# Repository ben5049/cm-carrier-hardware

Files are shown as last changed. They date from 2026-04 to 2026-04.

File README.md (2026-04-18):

# Compute Module 5 Carrier Board (WIP)

Compact CM5 carrier board with an M.2 E-key connector and a 1000BASE-T1 Ethernet PHY, as well as other optional IO.

- V1 Uses a separate PCIe switch and PCIe-to-Ethernet bridge. It has been abandoned in favour of V2
- V2 Uses the PCI11010C which integrates a PCIe switch and Ethernet MAC, leading to space and power savings compared to V1

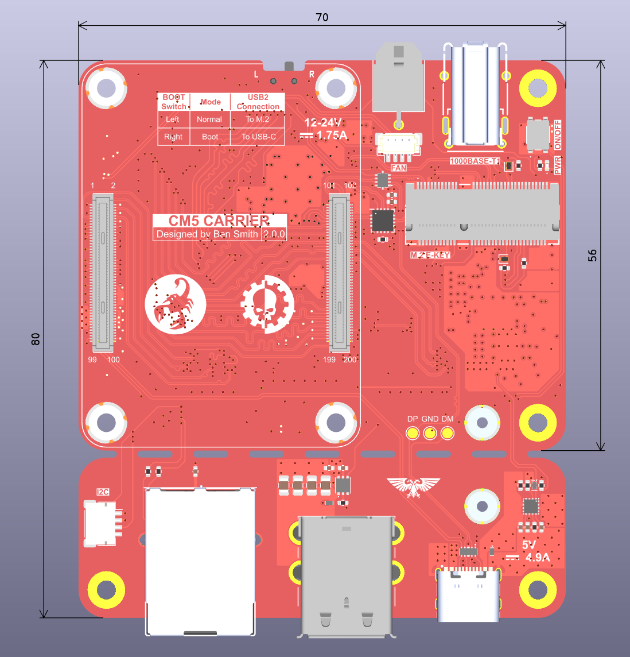
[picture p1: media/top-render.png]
top-render


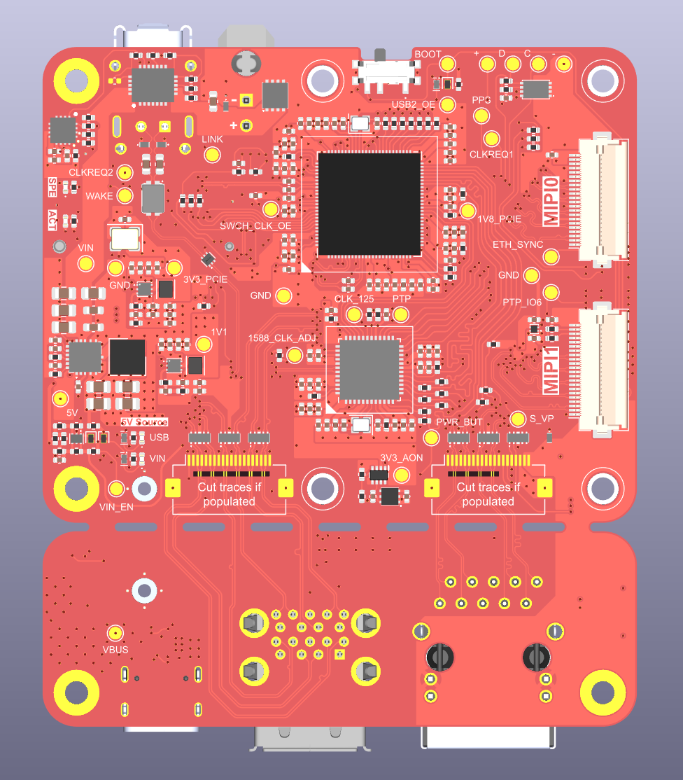
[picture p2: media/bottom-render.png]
bottom-render


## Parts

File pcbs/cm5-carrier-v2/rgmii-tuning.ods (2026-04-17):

tx | Post-r | Pre-r | total length | target | skew
d3 | 44.3194 | 3.2212 | 47.5406 | 44.3196 | 0.000199999999999534
d2 | 44.0708 | 3.4698 | 47.5406 | 44.071 | 0.000200000000006639
d1 | 43.8223 | 3.7183 | 47.5406 | 43.8225 | 0.000200000000006639
d0 | 43.5116 | 4.029 | 47.5406 | 43.5118 | 0.000200000000006639
ctl | 43.036 | 4.5048 | 47.5408 | 43.036 | 0
clk | 42.7582 | 4.7824 | 47.5406 | 42.7584 | 0.000199999999999534
rx | Post-r | Pre-r | total length | target | skew
d3 | 46.7064 | 4.7882 | 51.4946 | 46.7811 | 0.0747000000000071
d2 | 48.6547 | 2.9097 | 51.5644 | 48.6596 | 0.00490000000000634
d1 | 46.1052 | 5.4641 | 51.5693 | 46.1052 | 0
d0 | 46.9834 | 4.5618 | 51.5452 | 47.0075 | 0.0241000000000042
ctl | 46.8961 | 4.6096 | 51.5057 | 46.9597 | 0.0636000000000081
clk | 48.7847 | 2.7182 | 51.5029 | 48.8511 | 0.0664000000000016

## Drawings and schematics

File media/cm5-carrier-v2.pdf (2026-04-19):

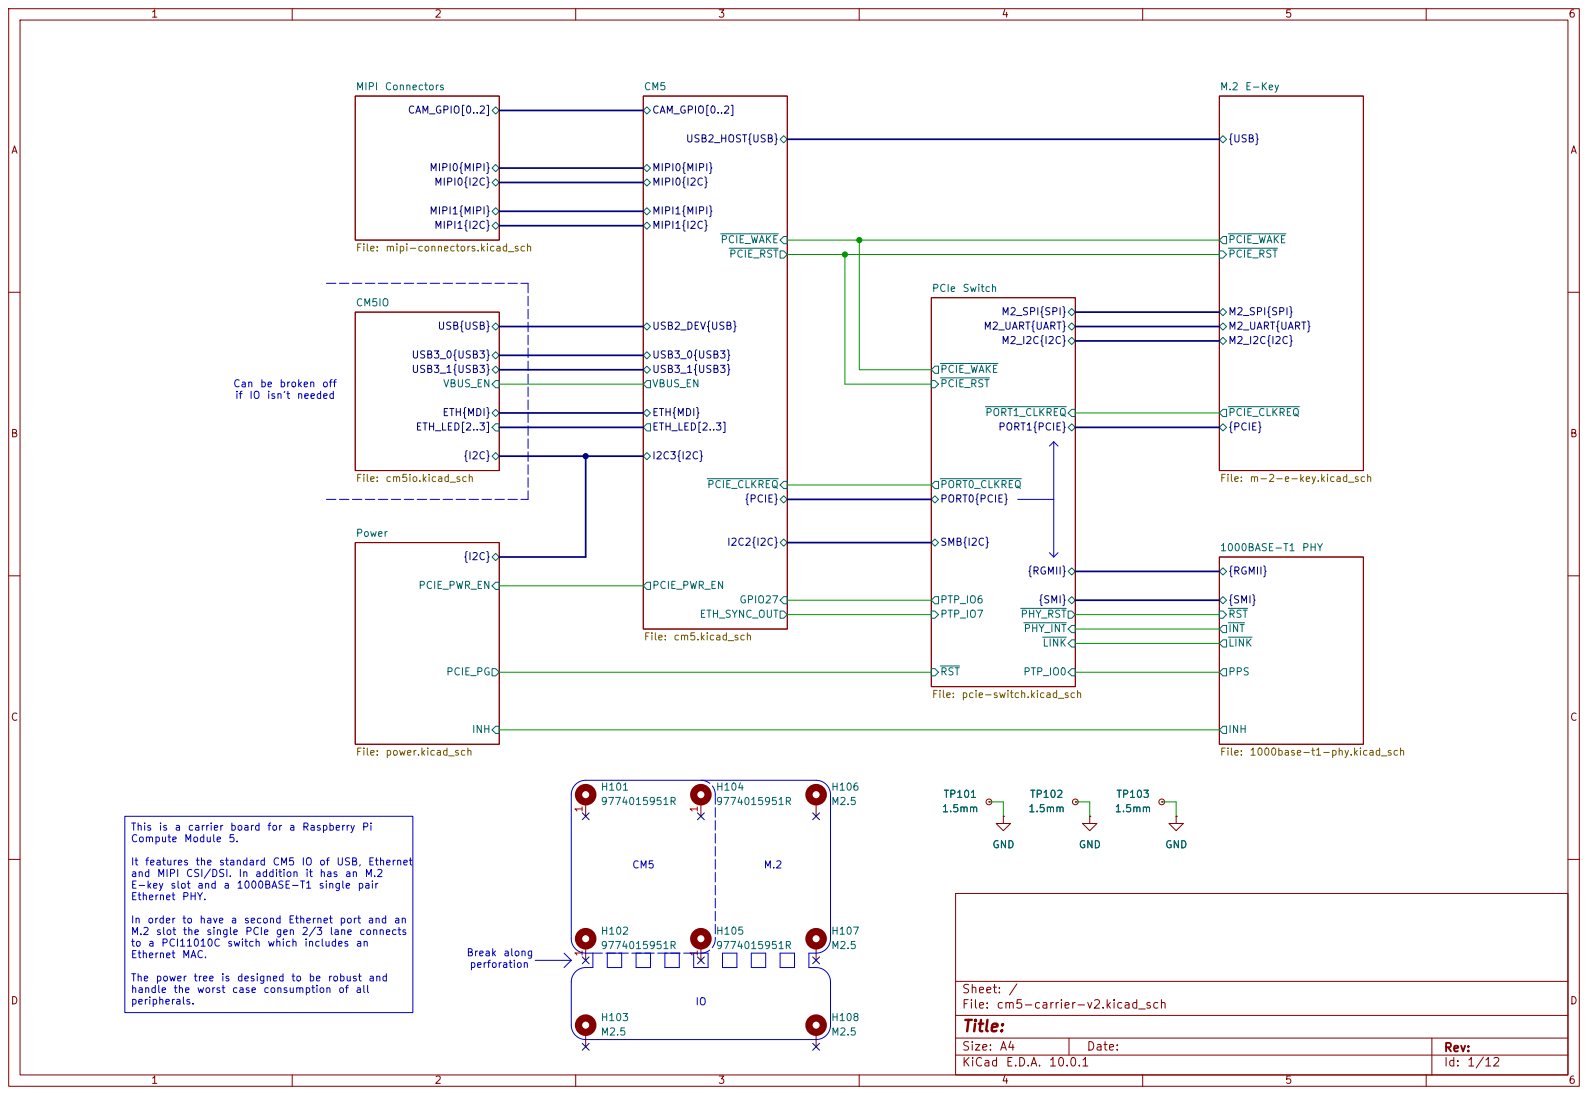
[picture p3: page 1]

CAM_GPIO[0..2] MIPI Connectors File: mipi-connectors.kicad_sch

M2_UART{UART} M.2 E-Key File: m-2-e-key.kicad_sch

Can be broken off
if IO isn't needed

This is a carrier board for a Raspberry Pi Compute Module 5.

It features the standard CM5 IO of USB, Ethernet and MIPI CSI/DSI. In addition it has an M.2

E-key slot and a 1000BASE-T1 single pair Ethernet PHY.

In order to have a second Ethernet port and an M.2 slot the single PCIe gen 2/3 lane connects

to a PCI11010C switch which includes an
Ethernet MAC. The power tree is designed to be robust and

Size: A4 | Rev:
KiCad E.D.A. 10.0.1 | Id: 1/12

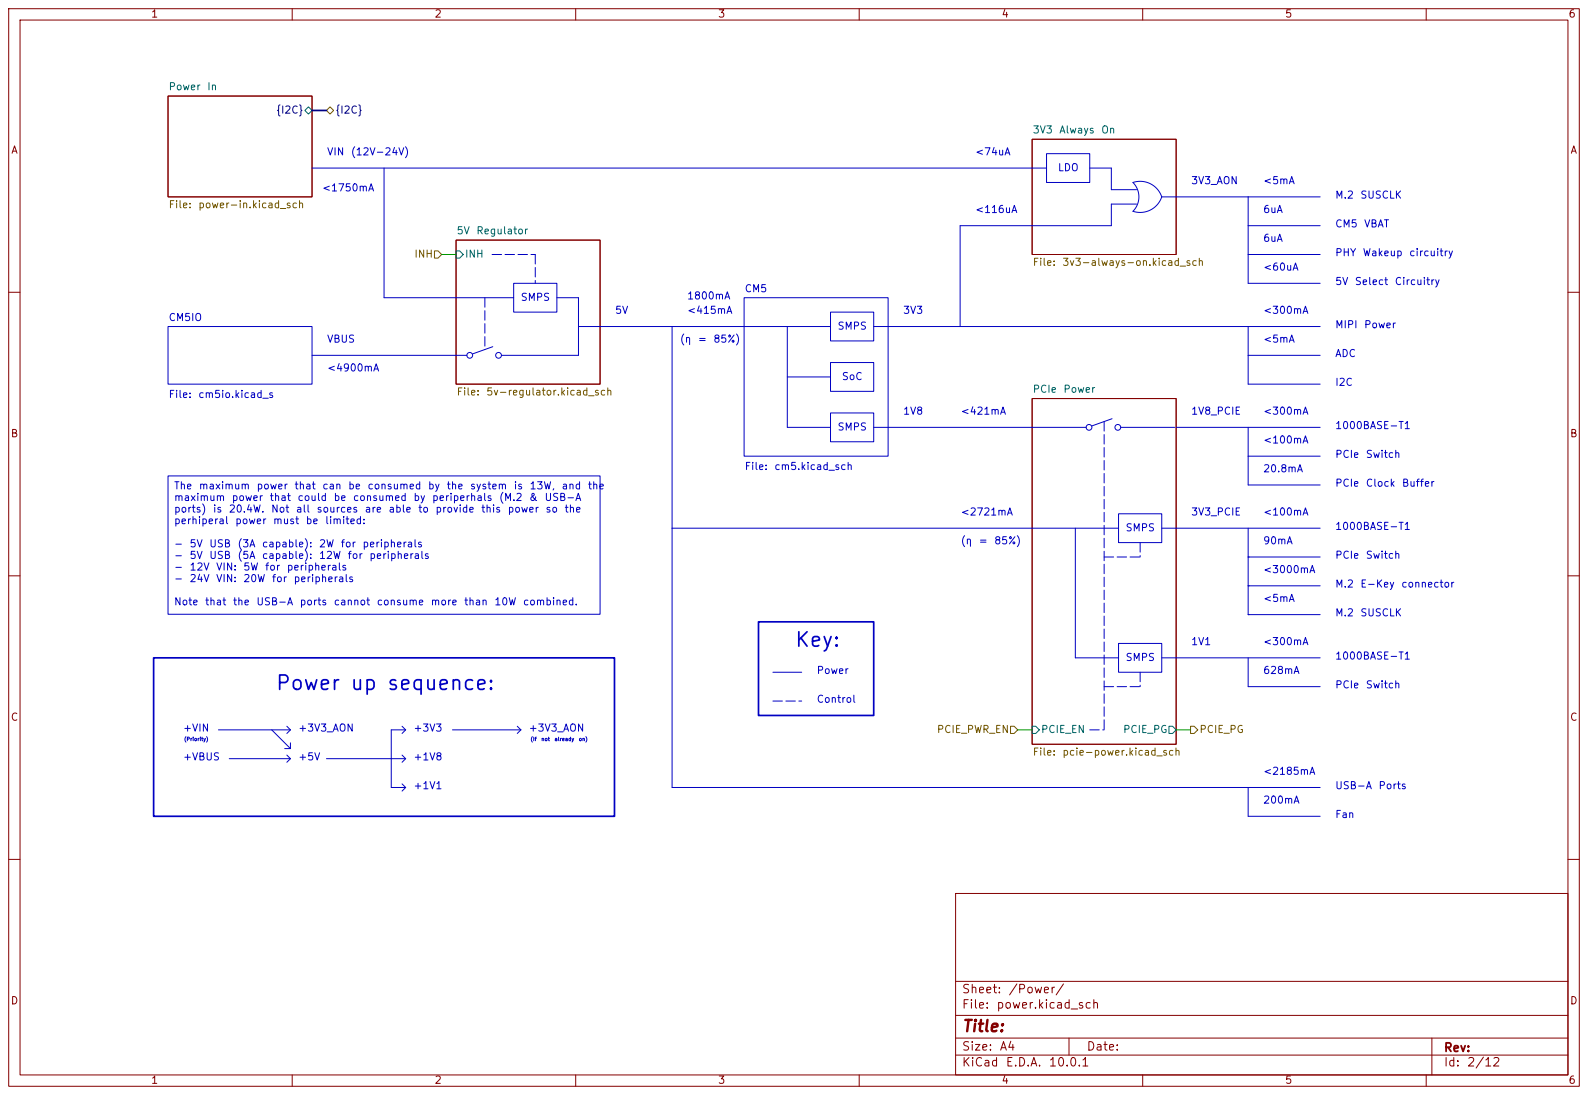
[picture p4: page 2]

5V Select Circuitry CM5 VBAT PCIe Switch 1000BASE-T1 PCIe Clock Buffer M.2 SUSCLK
ADC USB-A Ports 200mA <2185mA
PCIe Power File: pcie-power.kicad_sch

PHY Wakeup circuitry M.2 SUSCLK

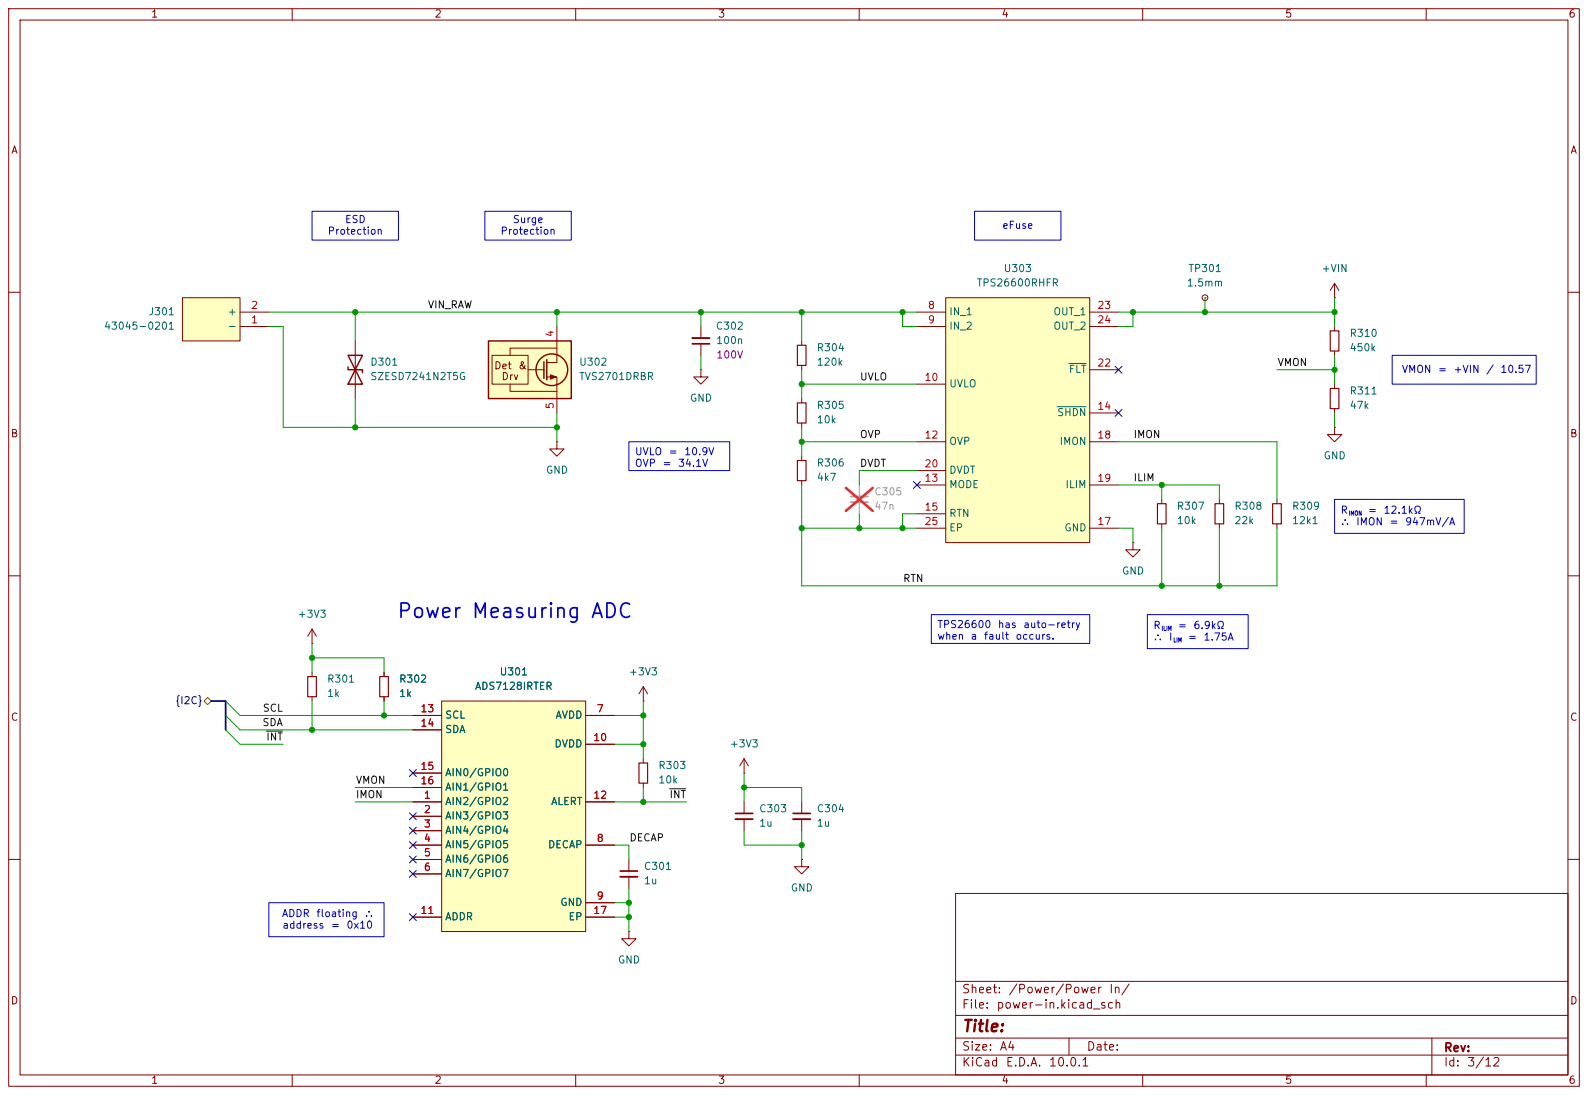
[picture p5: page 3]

eFuse UVLO = 10.9V OVP = 34.1V ESD
Protection

Surge Protection Power Measuring ADC

Sheet: /Power/Power In/
File: power-in.kicad_sch
Title:

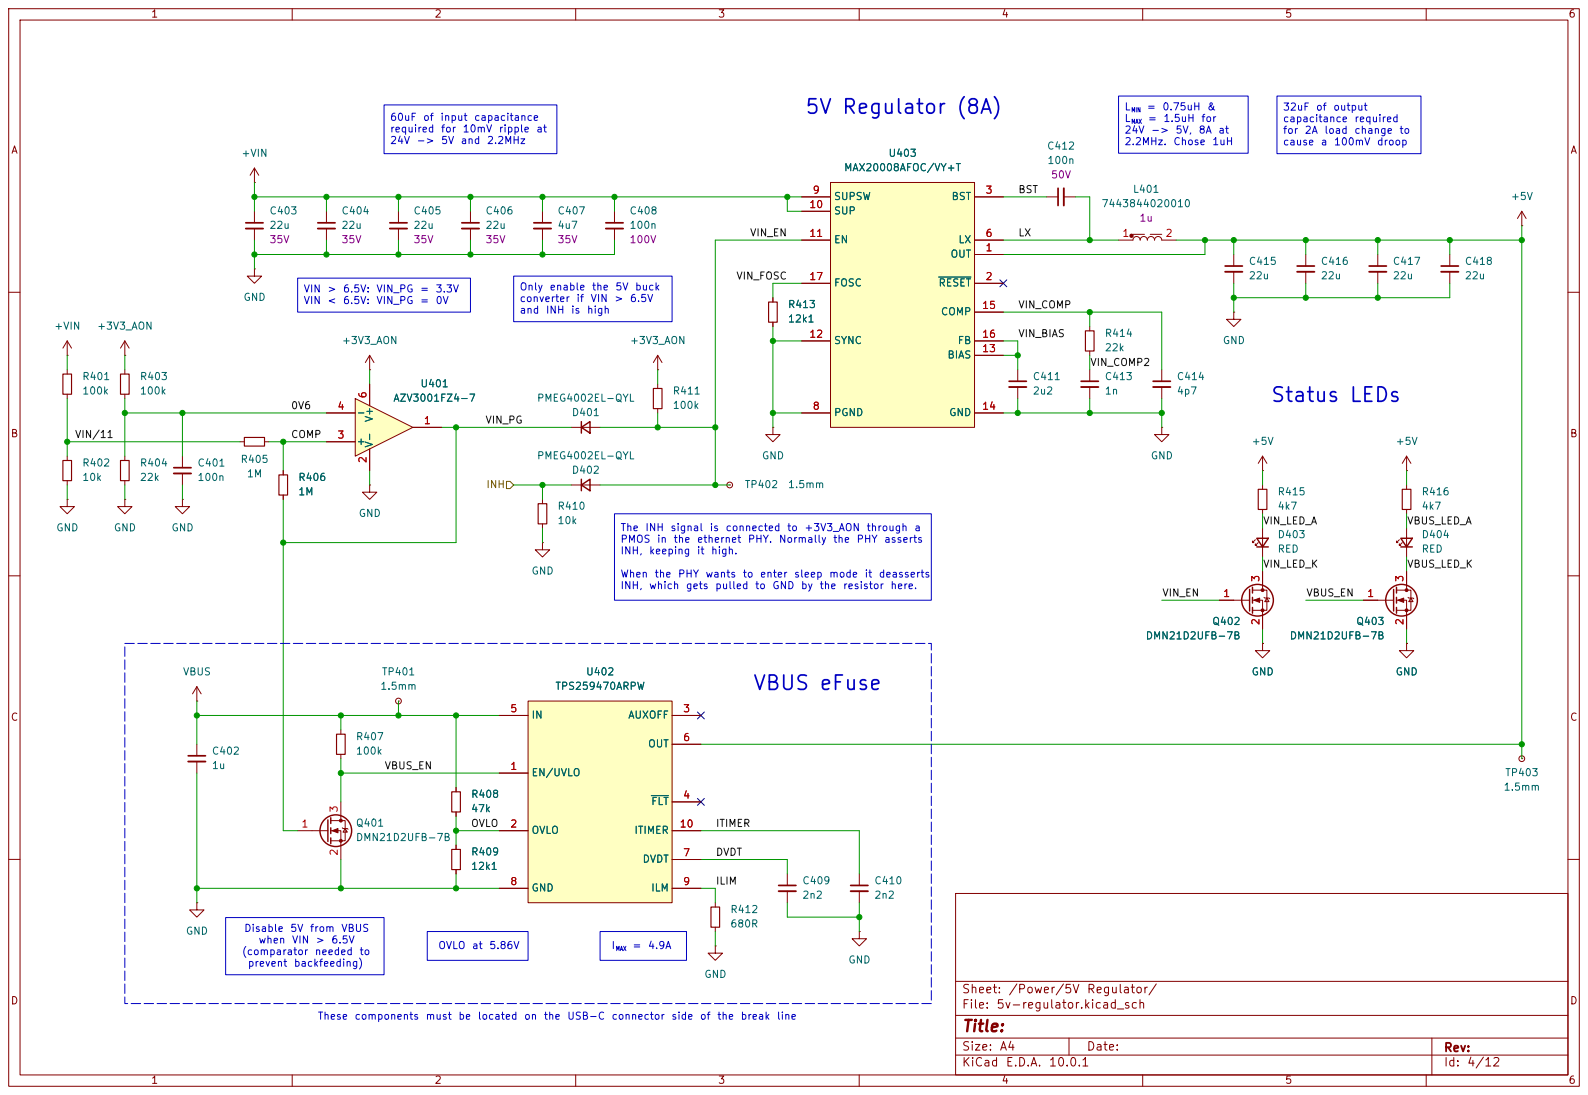
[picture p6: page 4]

L MIN = 0.75uH &
L MAX = 1.5uH for 24V -> 5V, 8A at 2.2MHz. Chose 1uH

32uF of output
capacitance required
for 2A load change to

cause a 100mV droop 60uF of input capacitance
required for 10mV ripple at 24V -> 5V and 2.2MHz

INH, which gets pulled to GND by the resistor here. Only enable the 5V buck converter if VIN > 6.5V and INH is high OVLO at 5.86V Disable 5V from VBUS when VIN > 6.5V
100k +3V3_AON

The INH signal is connected to +3V3_AON through a PMOS in the ethernet PHY. Normally the PHY asserts

INH, keeping it high. When the PHY wants to enter sleep mode it deasserts

These components must be located on the USB-C connector side of the break line VBUS eFuse

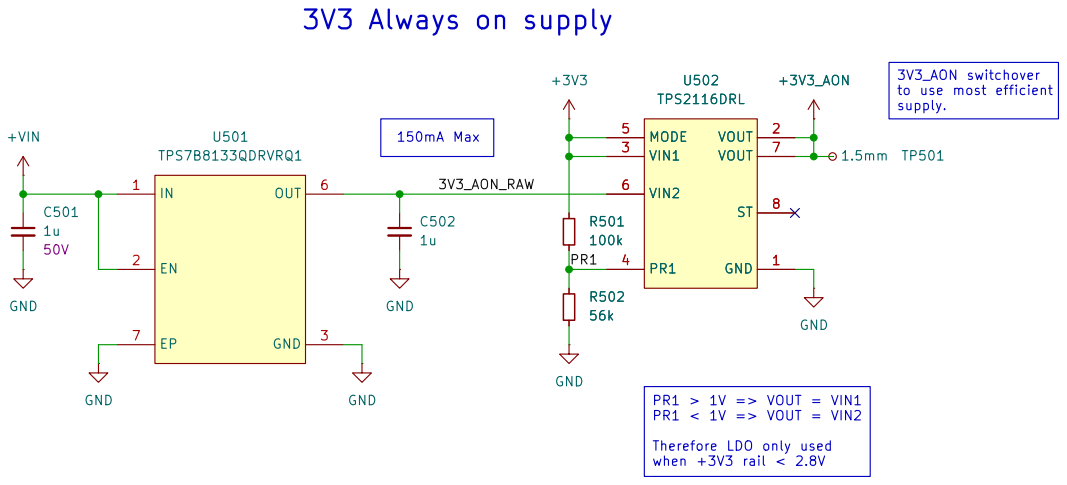
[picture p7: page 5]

to use most efficient supply. 150mA Max 3V3 Always on supply

Sheet: /Power/3V3 Always On/
File: 3v3-always-on.kicad_sch
Title:

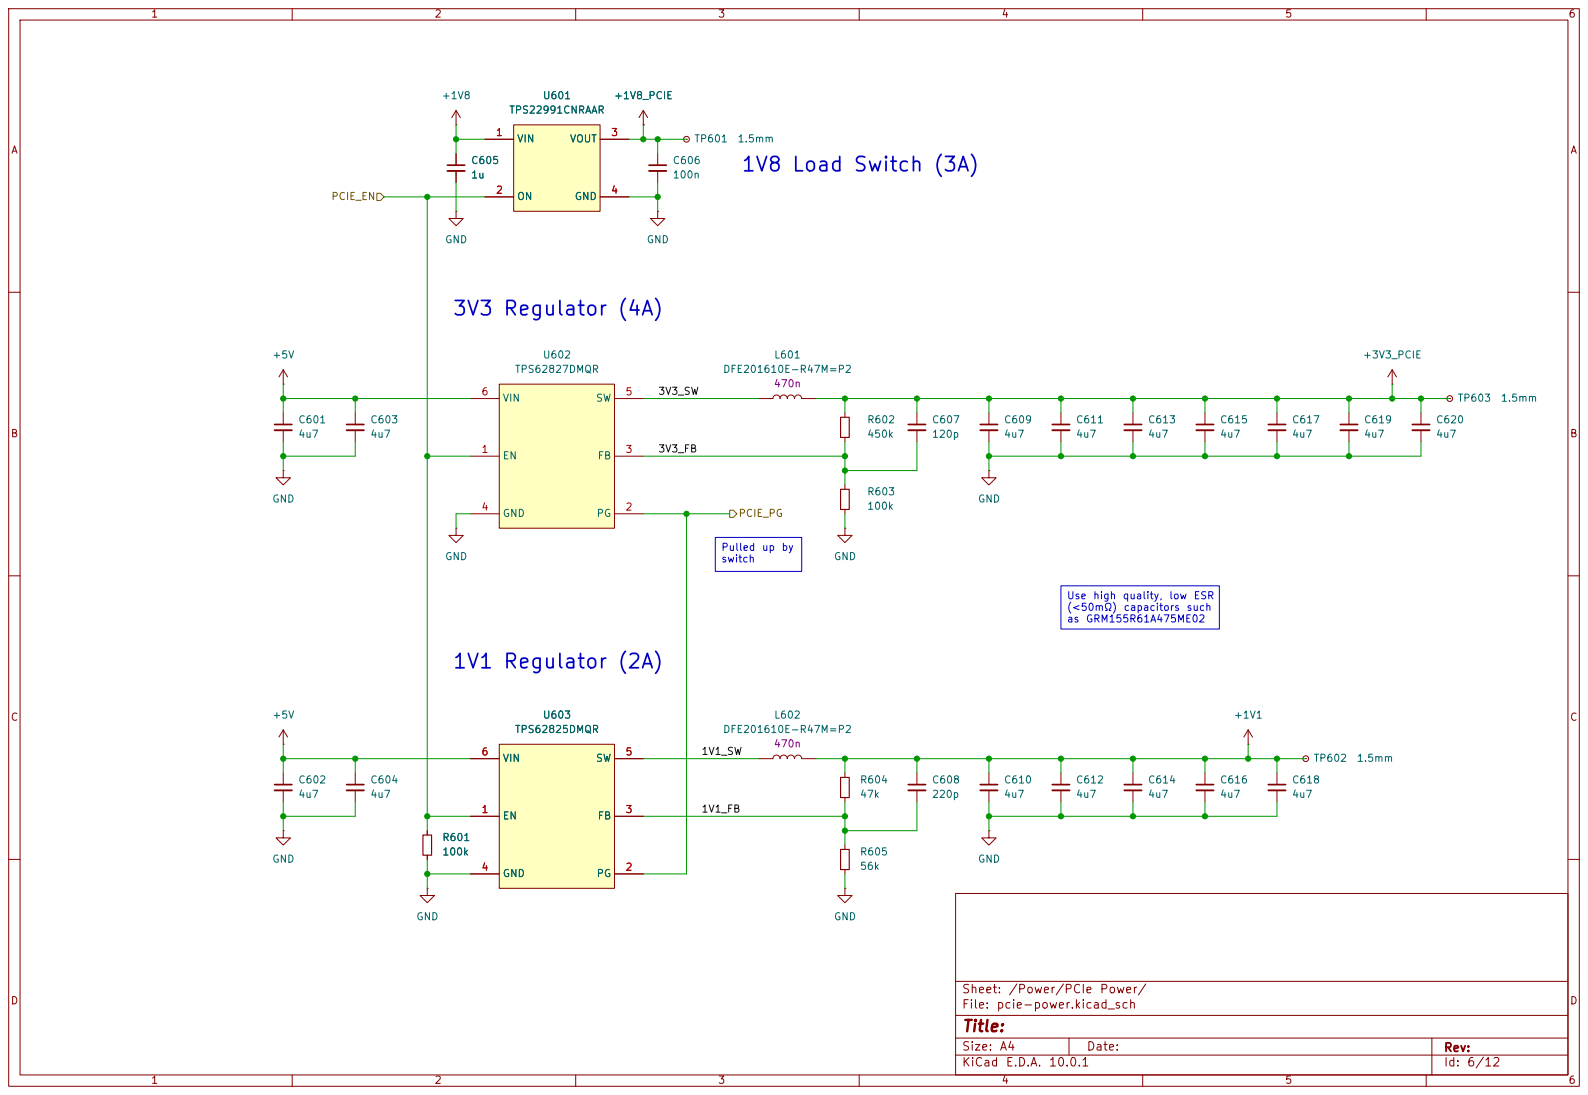
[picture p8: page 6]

Sheet: /Power/PCIe Power/
File: pcie-power.kicad_sch
Title:

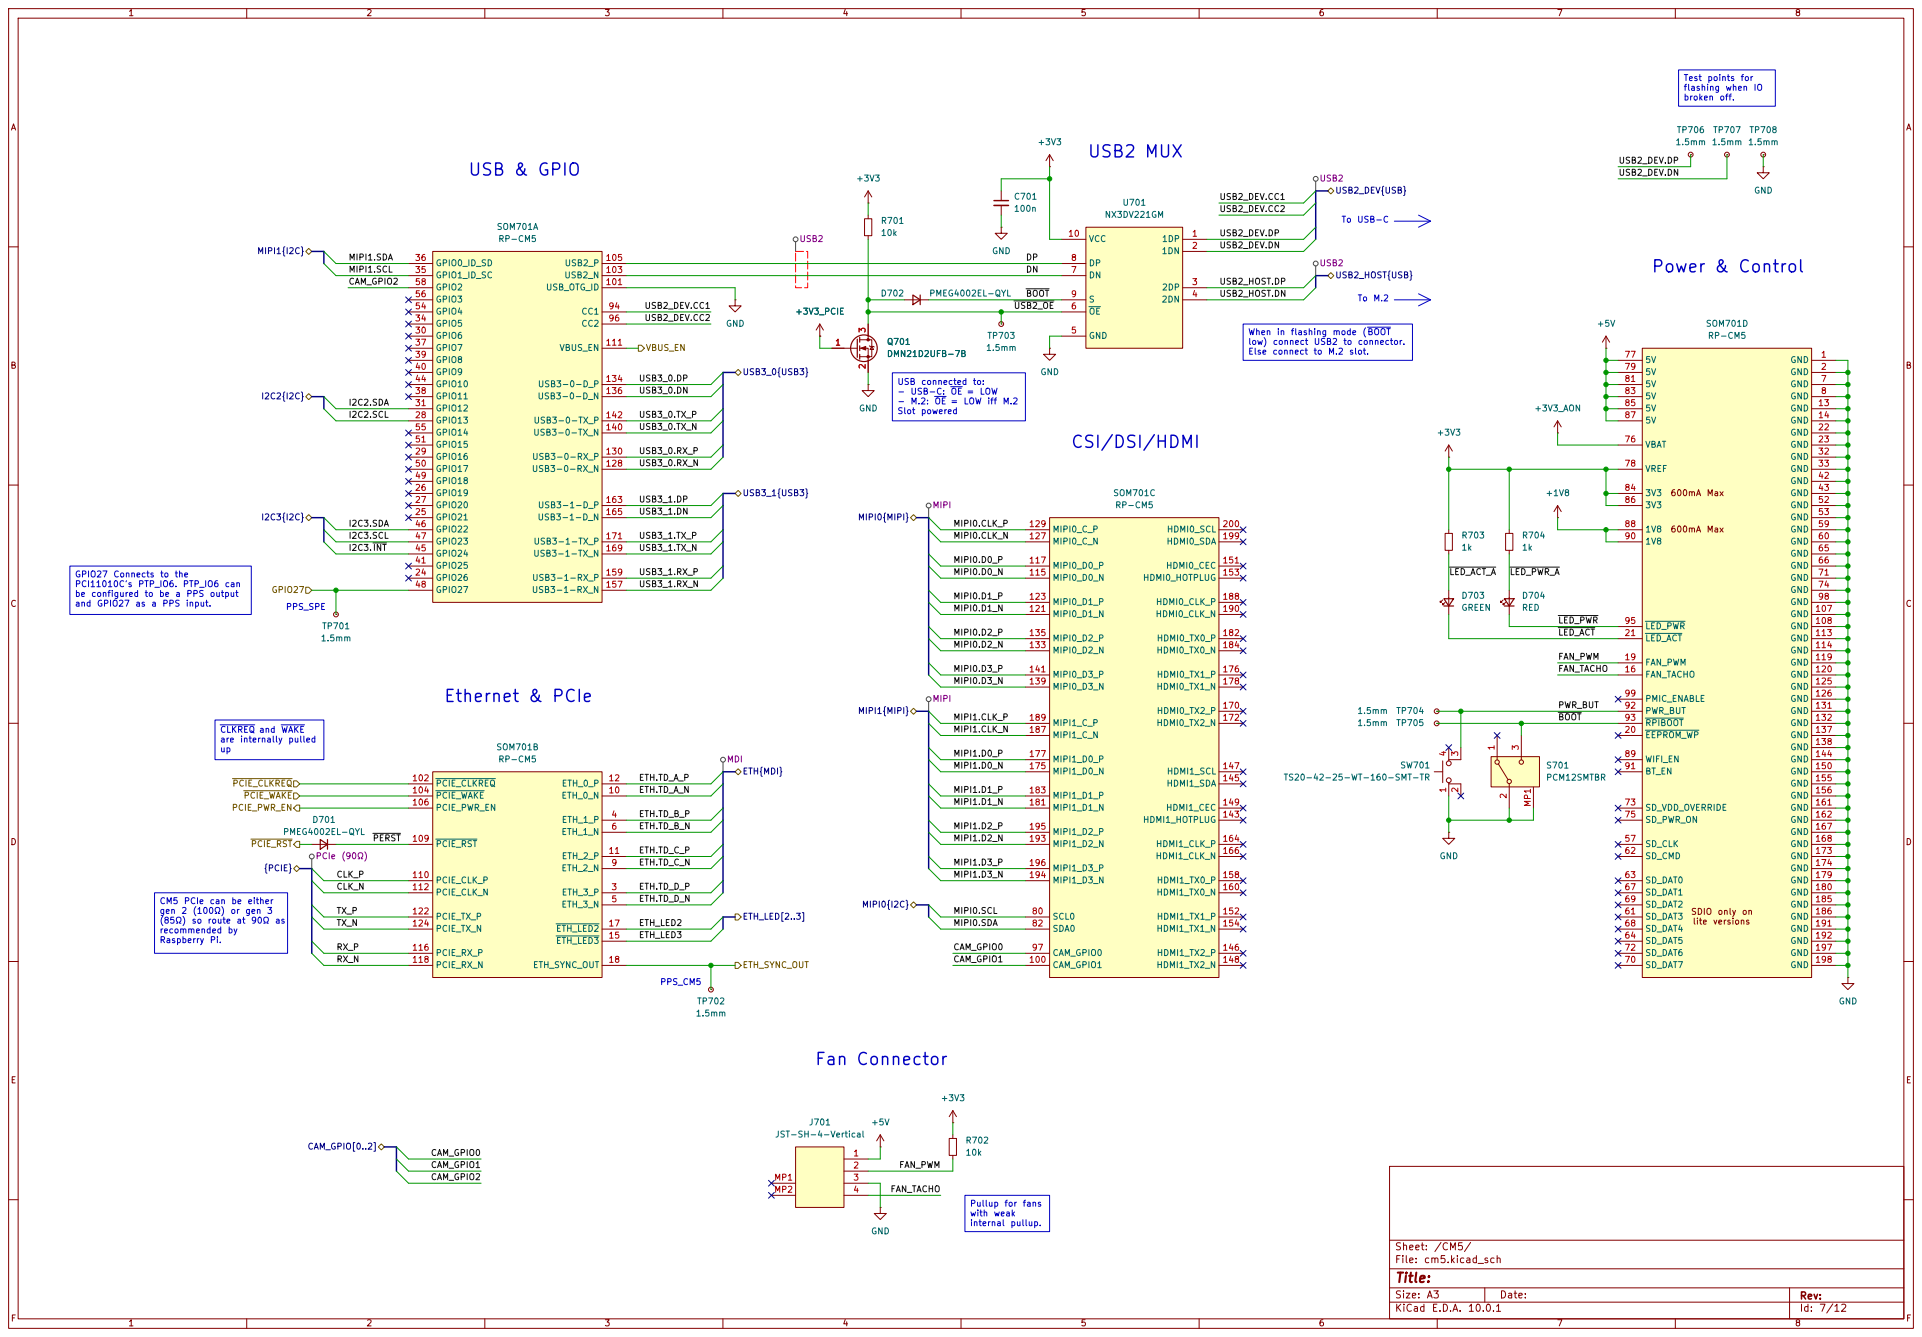
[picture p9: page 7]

broken off. USB connected to: - USB-C: OE = LOW - M.2: OE = LOW iff M.2

SOM701D
600mA Max 600mA Max SDIO only on

VREF 78 | 32 GND
3V3 84 | 33 GND 42 GND

up GPIO27 Connects to the PCI11010C's PTP_IO6. PTP_IO6 can

internal pullup. PPS_CM5 Ethernet & PCIe

Raspberry Pi.CLKREQ and WAKE

CM5 PCIe can be either gen 2 (100Ω) or gen 3

(85Ω) so route at 90Ω as
recommended by

Pullup for fans with weak

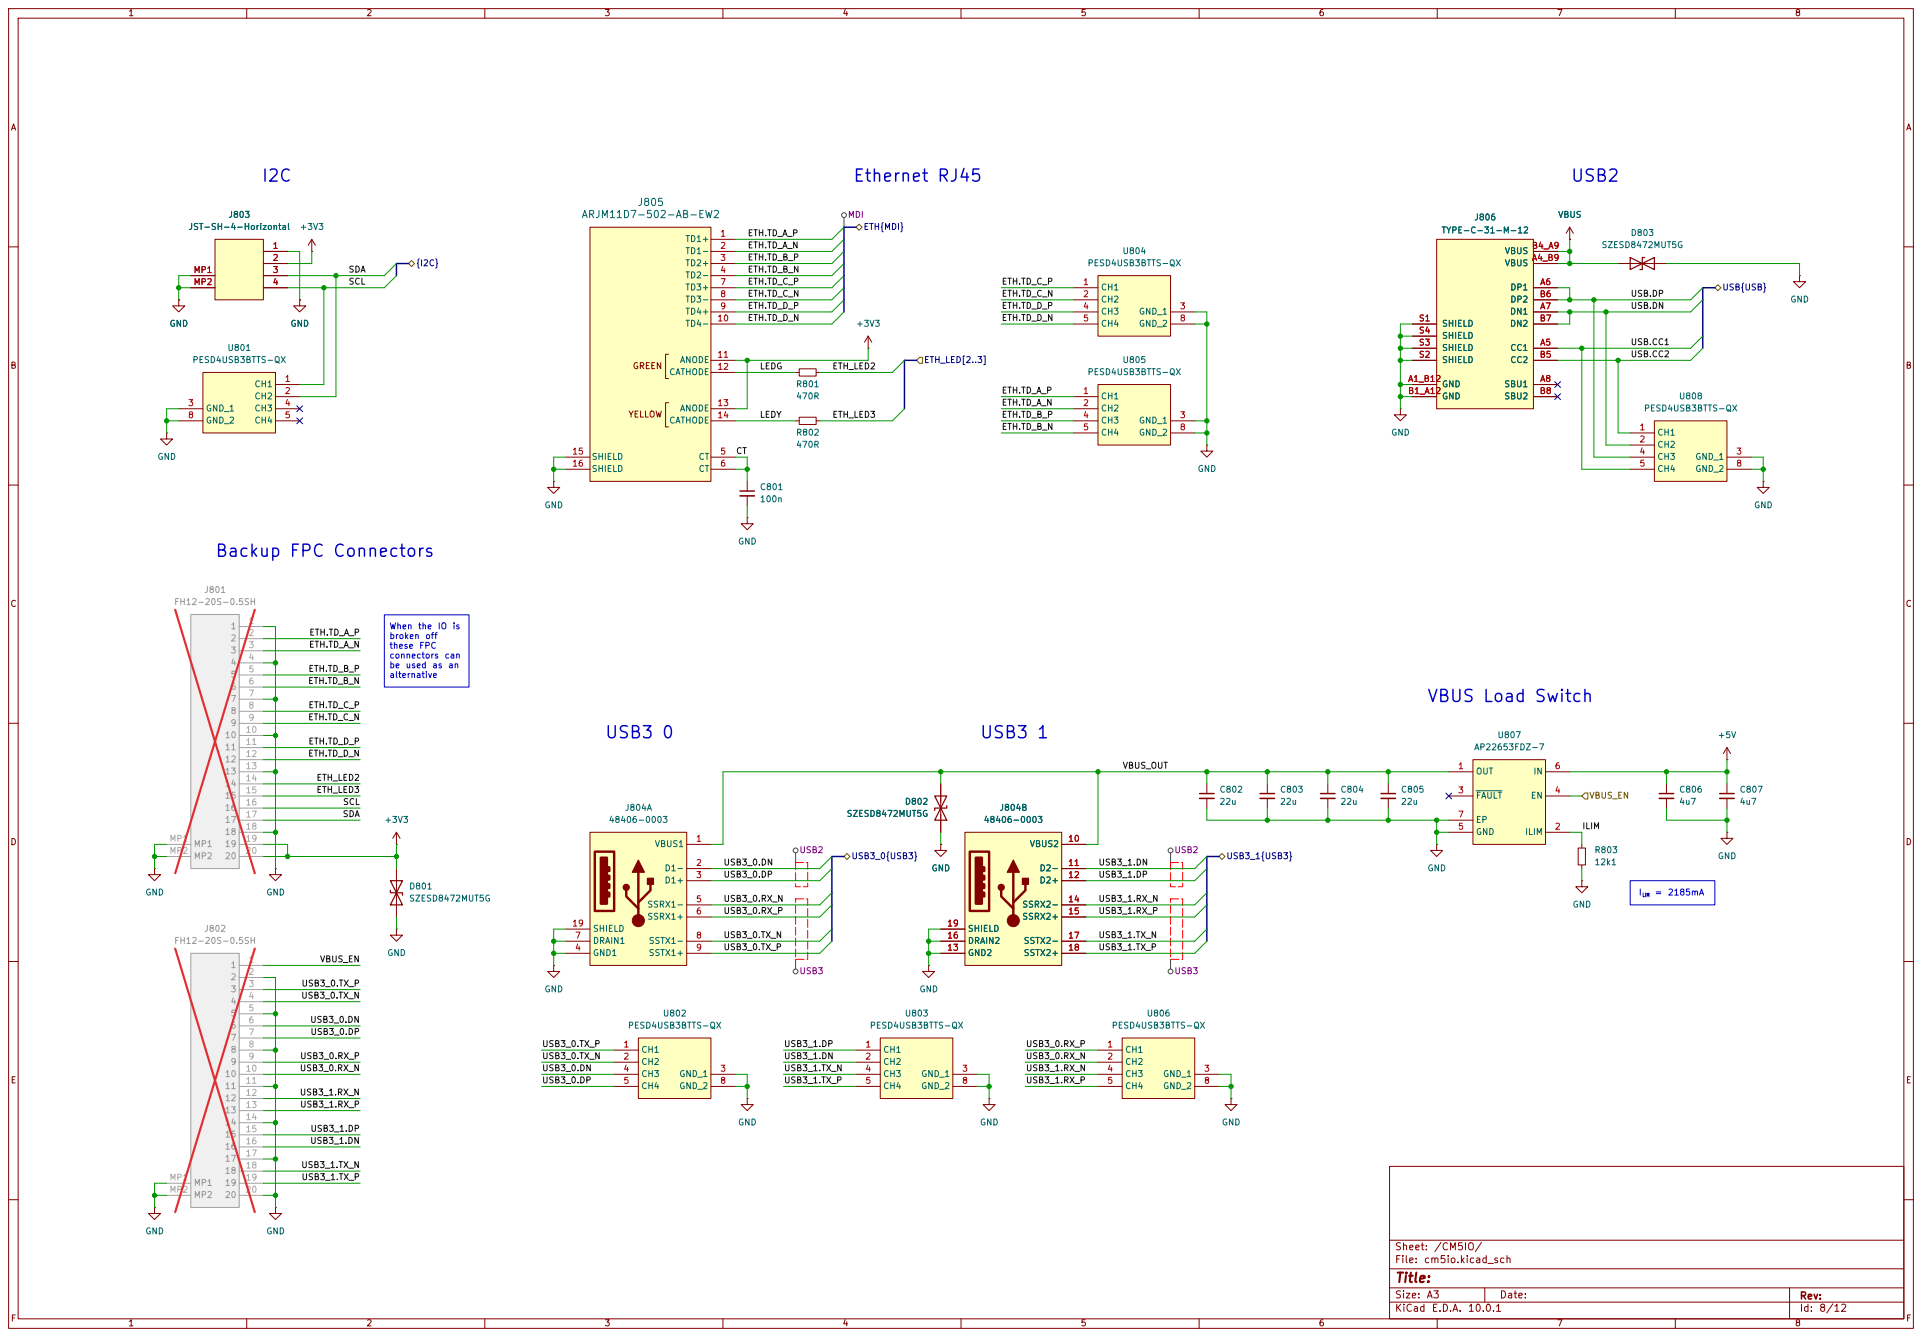
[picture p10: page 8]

When the IO is broken off

these FPC
connectors can
be used as an
alternative

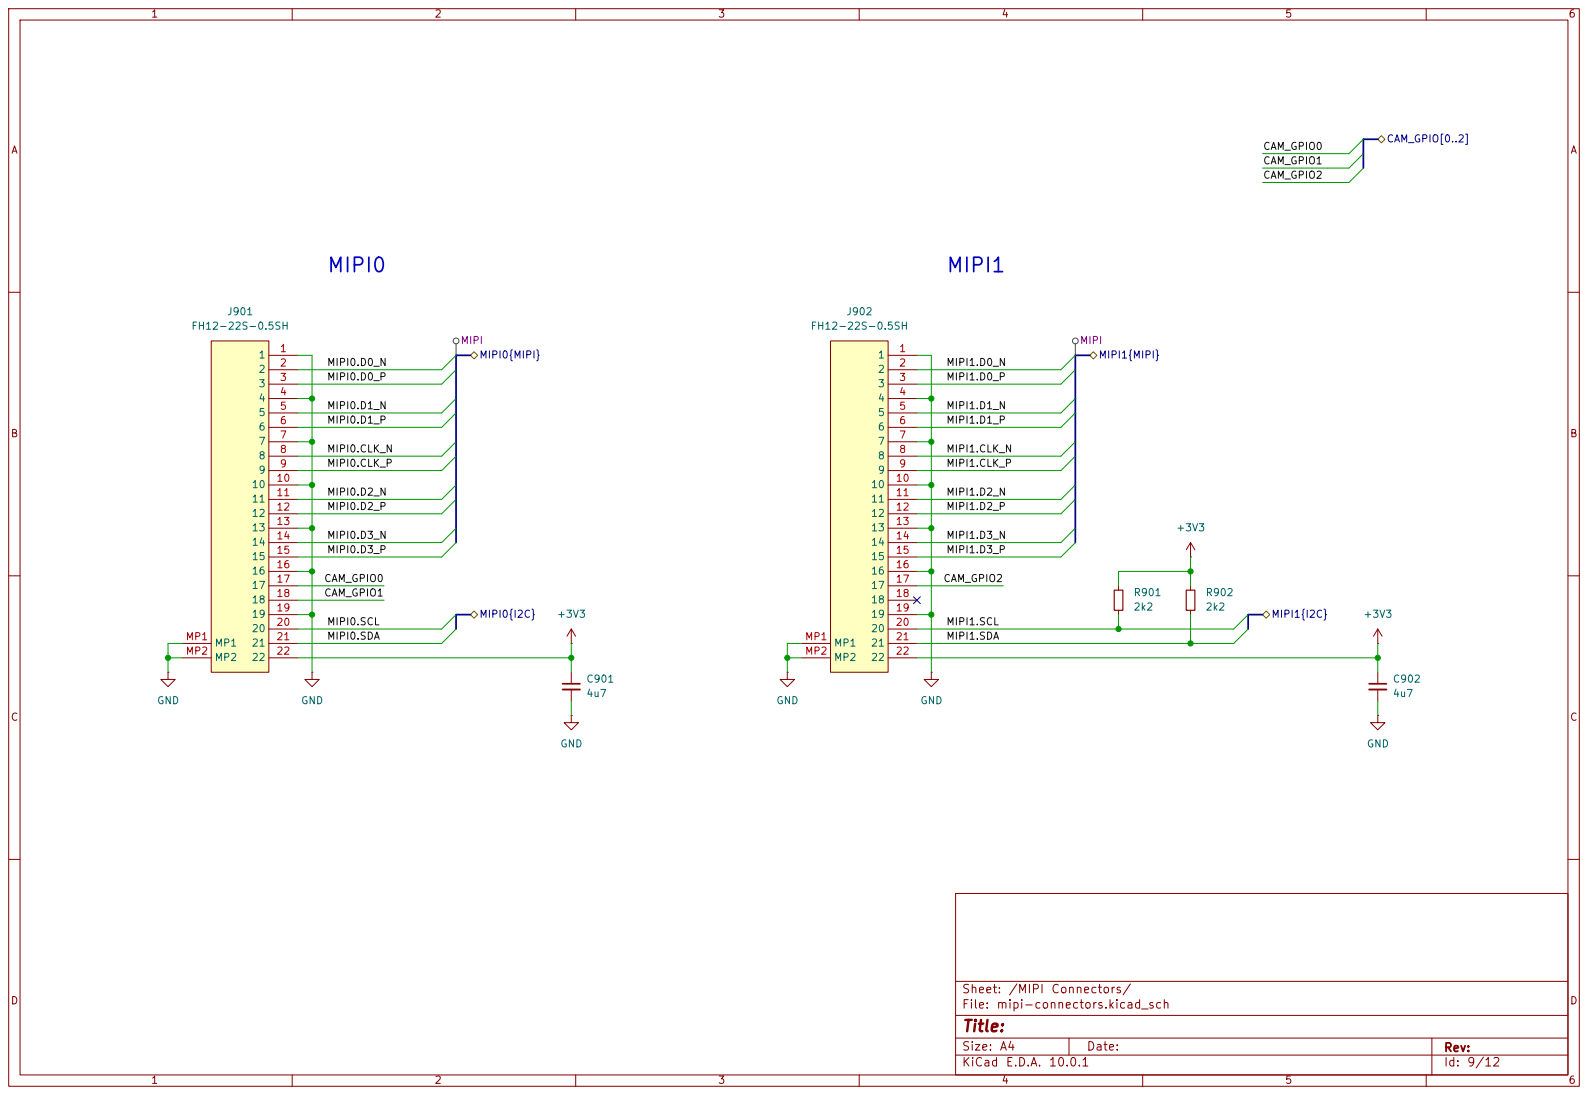
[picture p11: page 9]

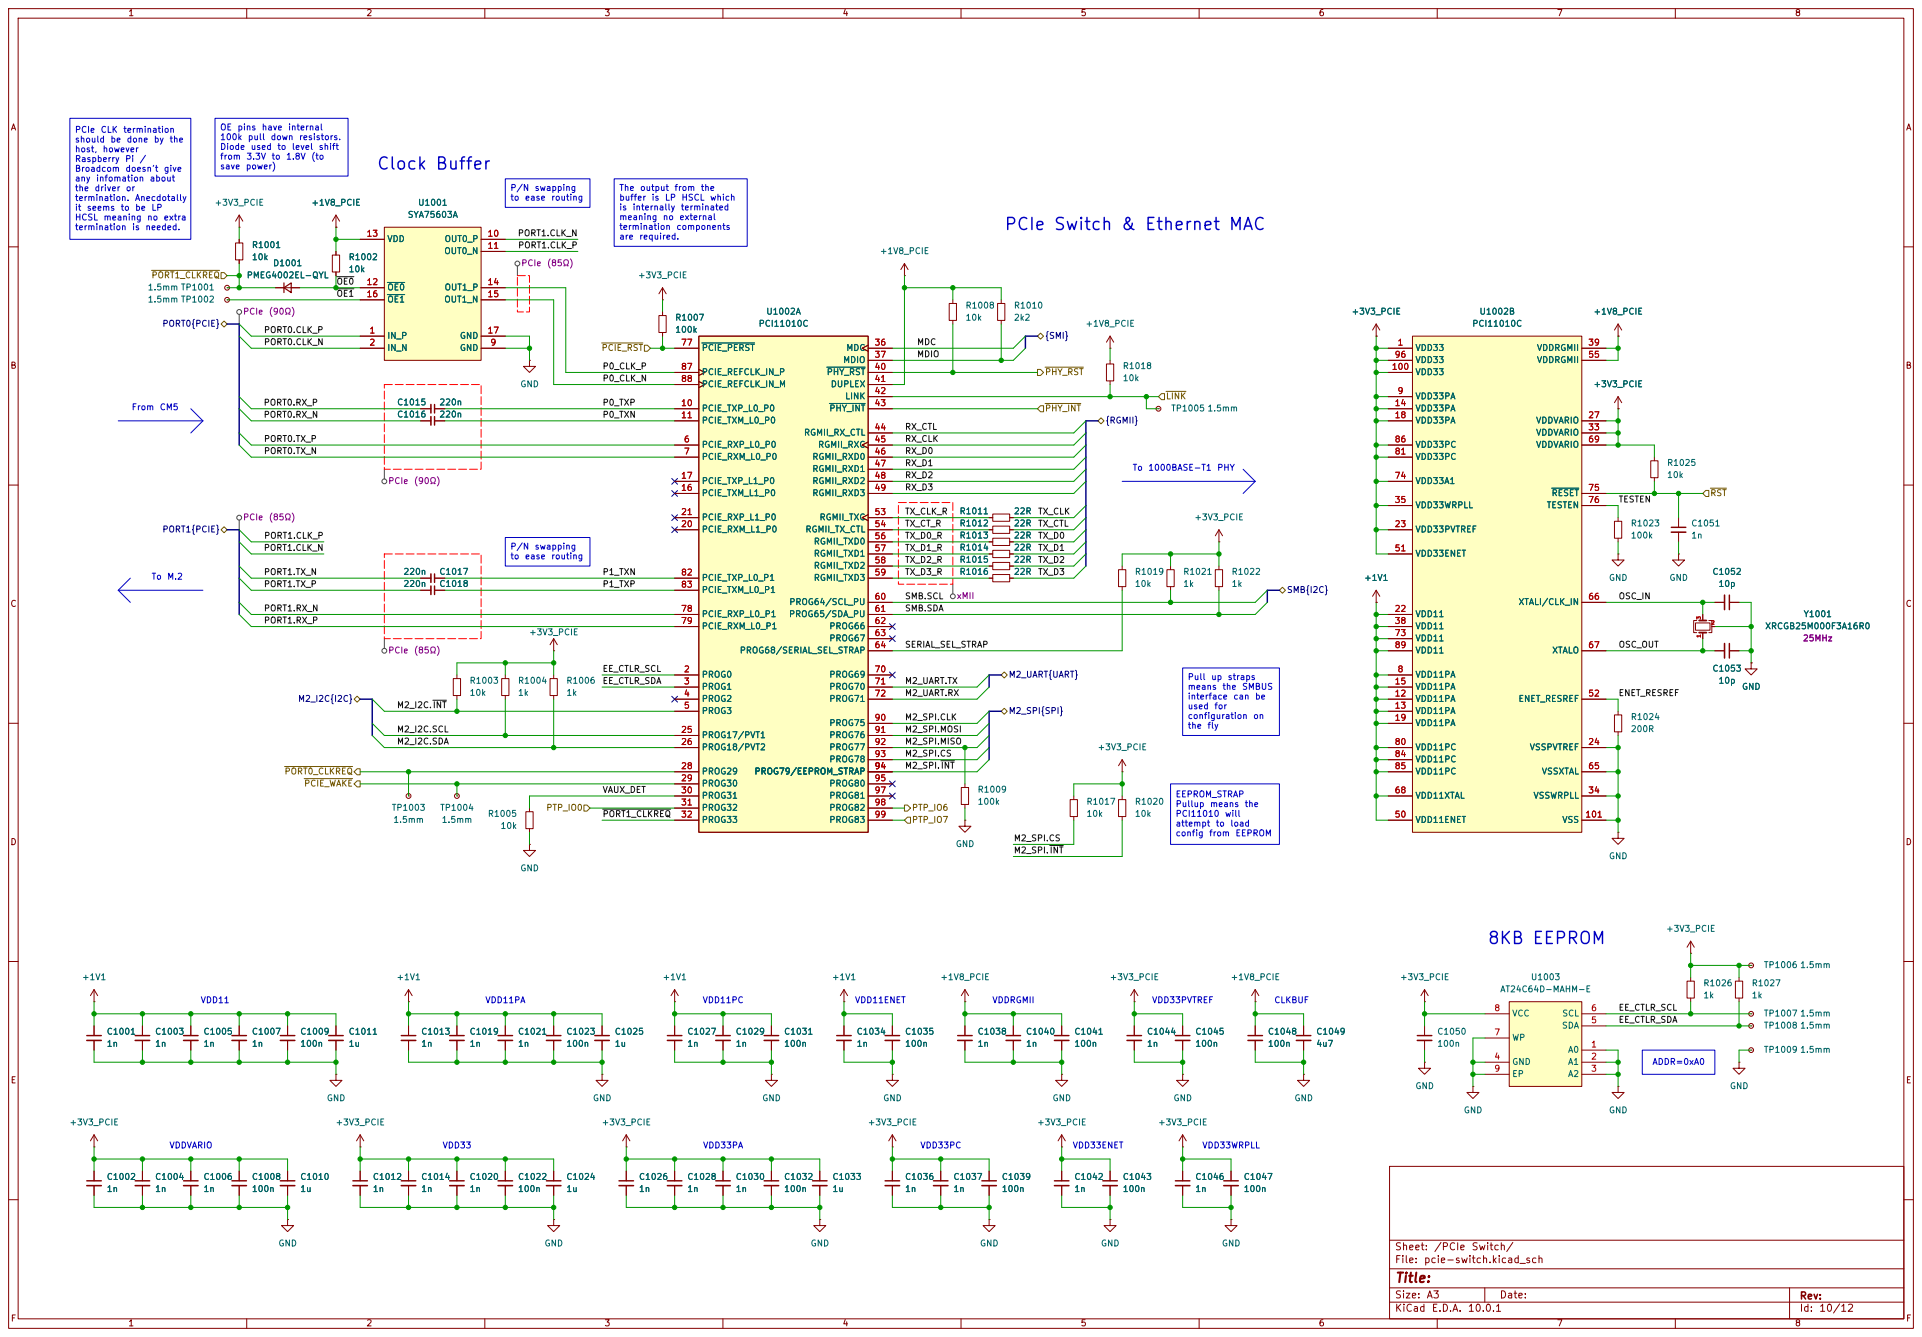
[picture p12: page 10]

PCIe CLK termination
should be done by the host, however Raspberry Pi /

to ease routing OE pins have internal 100k pull down resistors. Diode used to level shift

Broadcom doesn't give any infomation about

the driver or
termination. Anecdotally
it seems to be LP HCSL meaning no extra

is internally terminated meaning no external termination components are required.
M2_UART{UART} TX_CLK MDC

PCIe Switch & Ethernet MAC

Pull up straps means the SMBUS

interface can be used for configuration on

EEPROM_STRAP
Pullup means the PCI11010 will attempt to load

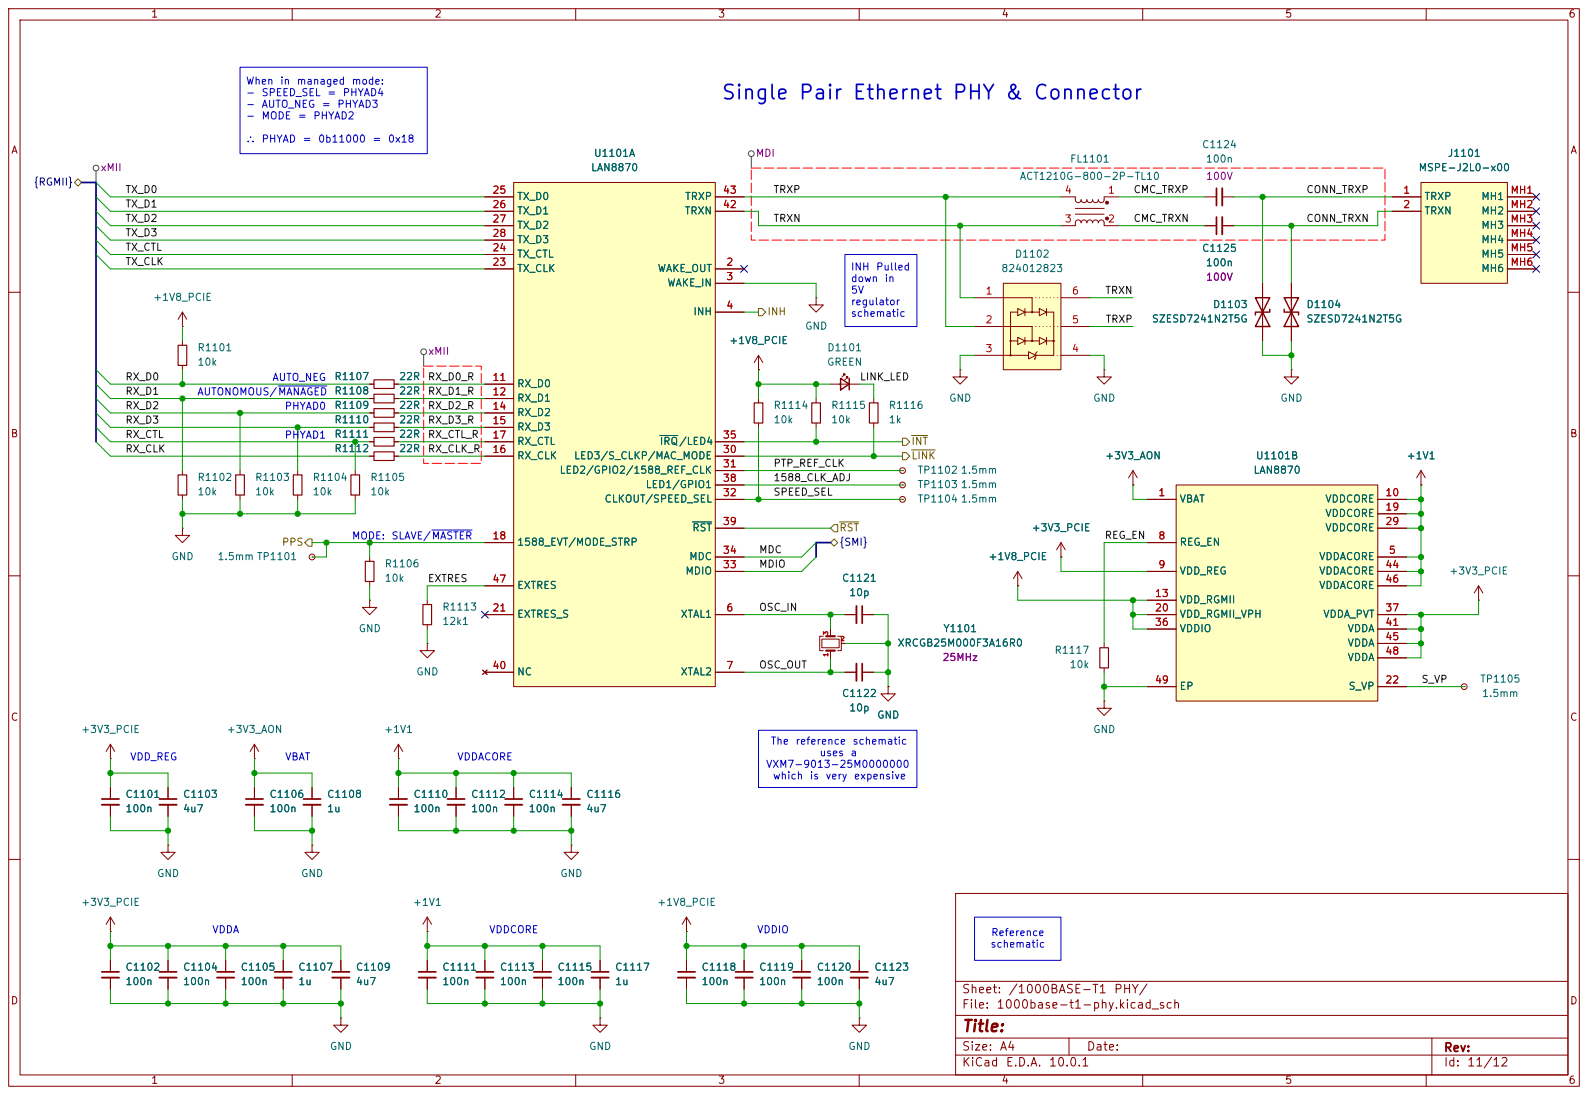
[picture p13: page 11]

When in managed mode: - SPEED_SEL = PHYAD4 - AUTO_NEG = PHYAD3 - MODE = PHYAD2 ∴ PHYAD = 0b11000 = 0x18

RX_CTL_R

R1112 | 22R | RX_CLK_R

The reference schematic uses a

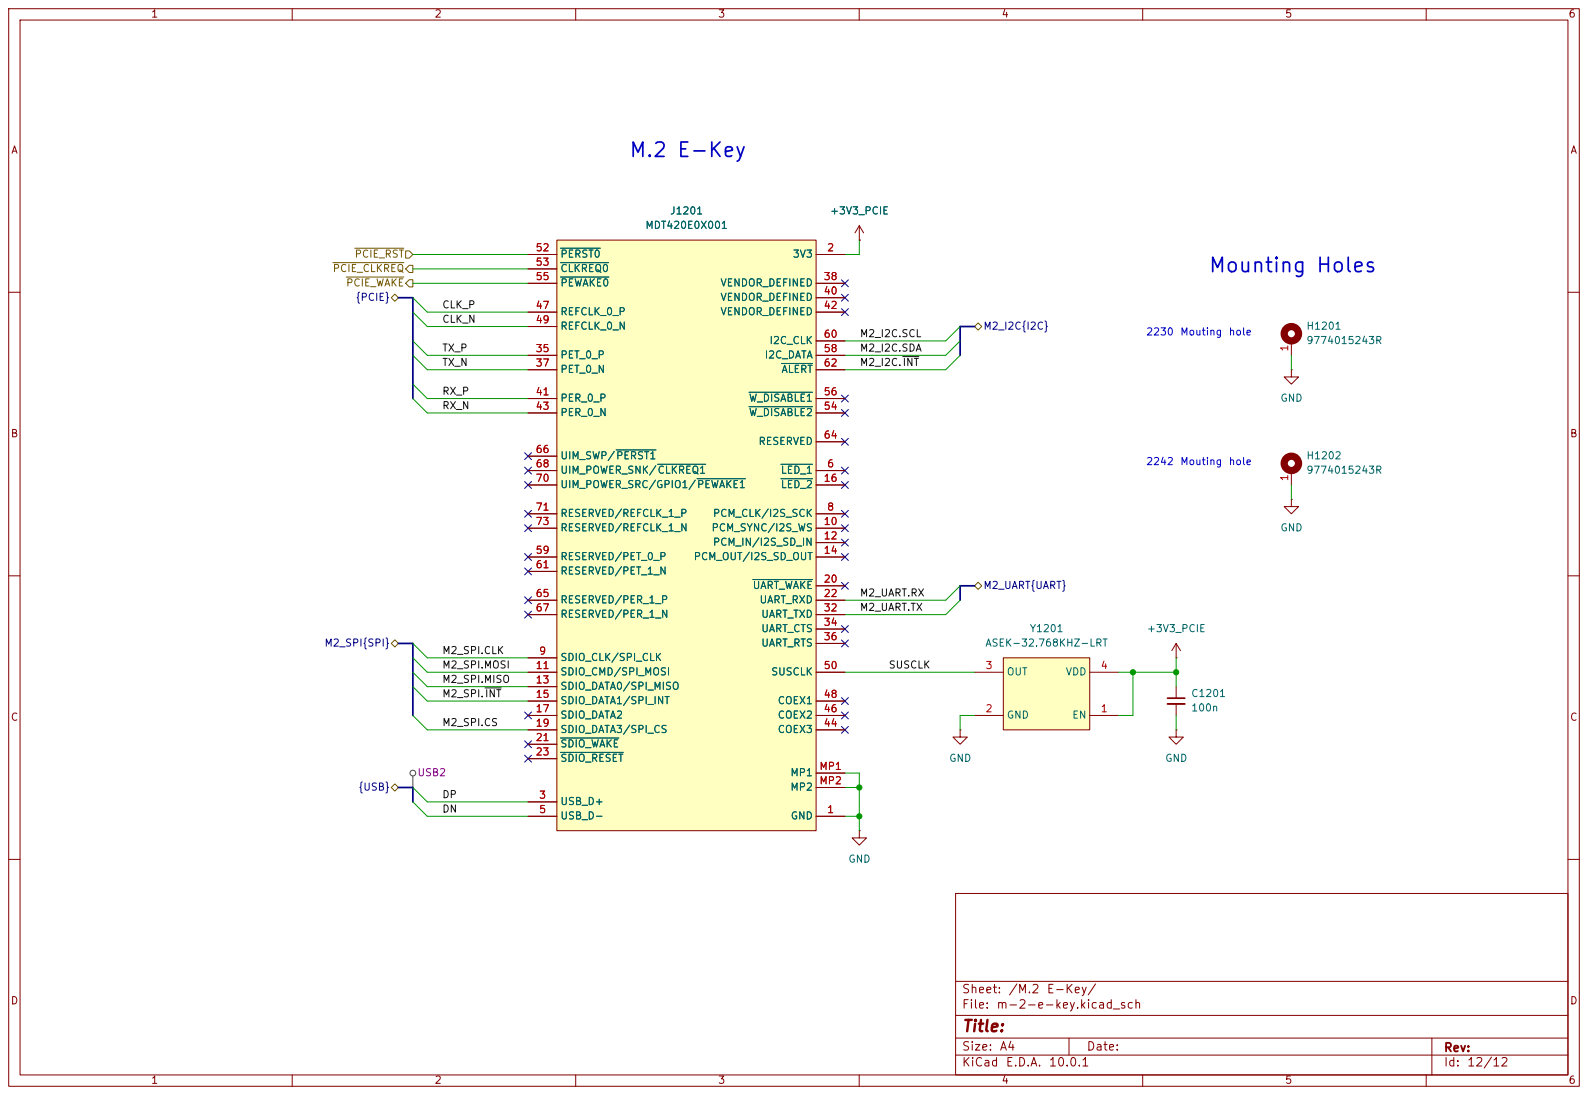
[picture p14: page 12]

DNM2_SPI. INT M2_SPI.CS M2_SPI.MISO M2_SPI.MOSI CLK_P

2242 Mouting hole 2230 Mouting hole Mounting Holes

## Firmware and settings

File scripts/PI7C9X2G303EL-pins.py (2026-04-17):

pins = """
A2 NC C35 NC AA35 CGND AR21 TEST6
A4 NC D1 NC AB1 NC AR23 PL_512B
A6 NC D37 NC AB37 REFCLKO_P[2] AR25 NC
A8 NC E3 VDDR AC3 NC AR27 NC
A10 PETP[0] E35 VDDR AC35 NC AR29 CLKBUF_PD
A12 PETN[0] F1 DWNRST_L[1] AD1 TEST4 AR31 VDDR
A14 NC F37 NC AD37 REFCLKO_N[2] AR33 NC
A16 NC G3 NC AE3 RXPOLINV_DIS AR35 NC
A18 REXT G35 TRST_L AE35 REFCLKI_P AT1 NC
A20 NC H1 NC AF1 TEST5 AT37 NC
A22 REFCLKN H37 TMS AF37 NC AU2 NC
A24 REFCLKP J3 DWNRST_L[2] AG3 NC AU4 NC
A26 PERN[2] J35 TDI AG35 SCAN_EN AU6 GPIO[1]
A28 PERP[2] K1 NC AH1 SMBCLK AU8 GPIO[2]
A30 NC K37 TCK AH37 REFCLKI_N AU10 GPIO[4]
A32 NC L3 VDDR AJ3 PWR_SAV AU12 GPIO[5]
A34 NC L35 VDDC AJ35 EECLK AU14 GPIO[7]
A36 NC M1 PERST_L AK1 SMBDATA AU16 SLOT_IMP[2]
B1 NC M37 DGND AK37 EEPD AU18 NC
B37 NC N3 TEST1 AL3 NC AU20 NC
C3 NC N35 TDO AL35 PORTSTATUS[1] AU22 NC
C5 NC P1 VDDCAUX AM1 NC AU24 NC
C7 NC P37 REFCLKO_P[0] AM37 PORTSTATUS[2] AU26 NC
C9 PERP[0] R3 VDDCAUX AN3 NC AU28 NC
C11 PERN[0] R35 IREF AN35 VDDC AU30 DGND
C13 NC T1 TEST2 AP1 NC AU32 VDDR
C15 REXT_GND T37 REFCLKO_N[0] AP37 PORTSTATUS[0] AU34 NC
C17 AVDDH U3 VAUX AR3 NC AU36 NC
C19 AGND U35 NC AR5 NC T AVDD
C21 AGND V1 TEST3 AR7 SLOTCLK B VDDC
C23 PETN[2] V37 REFCLKO_P[1] AR9 GPIO[0] R CVDDR
C25 PETP[2] W3 VC1_EN AR11 GPIO[3] L VDDC
C27 PETN[1] W35 CGND AR13 GPIO[6] GND VSS
C29 PETP[1] Y1 PRSNT[1] AR15 SLOT_IMP[1]
C31 PERN[1] Y37 REFCLKO_N[1] AR17 NC
C33 PERP[1] AA3 PRSNT[2] AR19 VDDR
"""

header = """(symbol "PI7C9X2G303EL"
	(exclude_from_sim no)
	(in_bom yes)
	(on_board yes)
	(property "Reference" "U"
		(at 0 2.54 0)
		(effects
			(font (size 1.27 1.27))
		)
	)
	(property "Value" ""
		(at 0 0 0)
		(effects
			(font (size 1.27 1.27))
		)
	)
	(property "Footprint" ""
		(at 0 0 0)
		(effects
			(font (size 1.27 1.27))
			(hide yes)
		)
	)
	(property "Datasheet" ""
		(at 0 0 0)
		(effects
			(font (size 1.27 1.27))
			(hide yes)
		)
	)
	(property "Description" ""
		(at 0 0 0)
		(effects
			(font (size 1.27 1.27))
			(hide yes)
		)
	)
	(property "ki_locked" ""
		(at 0 0 0)
		(effects
			(font (size 1.27 1.27))
		)
	)
	(symbol "PI7C9X2G303EL_1_1\""""

pin_template = """
		(pin PIN_TYPE line
			(at 0 -PIN_Y 0)
			(length 5.08)
			(name "PIN_NAME"
				(effects
					(font (size 1.27 1.27))
				)
			)
			(number "PIN_NUM"
				(effects
					(font (size 1.27 1.27))
				)
			)
		)"""

footer = """
	)
	(embedded_fonts no)
)"""


pin_mixed_list = pins.replace("\n", " ").split(" ")
key = ""
val = False
pin_table = {}
for pin in pin_mixed_list:
    if pin:
        if not val:
            key = pin
            val = True
        else:
            pin_table[key] = pin
            val = False


output = header

pin_y = 0
seen_nums = []
for num, name in pin_table.items():

    rendered_template = pin_template

    if name.count("["):
        
        name, index = name.split("[")
        index = int(index[:-1])

        if name[-2:] == "_N":
            name = f"{name[:-2]}_{index}_N"
        elif name[-2:] == "_P":
            name = f"{name[:-2]}_{index}_P"
        else:
            name = f"{name}{index}"
    
    print(str(num).ljust(10), name)

    if name == "NC":
        rendered_template = rendered_template.replace("PIN_TYPE", "no_connect")
    elif name in ("VDDC", "VDDR", "VDDCAUX", "VAUX", "AVDDH", "AVDD"):
        rendered_template = rendered_template.replace("PIN_TYPE", "power_in")
    else:
        rendered_template = rendered_template.replace("PIN_TYPE", "passive")

    rendered_template = rendered_template.replace("PIN_NAME", name)
    rendered_template = rendered_template.replace("PIN_NUM", num)
    rendered_template = rendered_template.replace("PIN_Y", str(pin_y))

    output += rendered_template

    pin_y = round(pin_y + 2.54, 2)
    assert num not in seen_nums
    seen_nums.append(num)
    

output += footer

with open("pins.txt", "w") as file:
    file.write(output)

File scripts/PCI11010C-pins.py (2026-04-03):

table = """1 VDD33 P 51 VDD33ENET P
2 PROG0 Z 52 ENET_RESREF IR
3 PROG1 Z 53 PROG58/RGMII_TXC/RMII_REF_CLK_OUT Z
4 PROG2 Z 54 PROG59/RGMII_TX_CTL/RMII_TX_EN Z
5 PROG3 Z 55 VDDRGMII P
6 PCIE_RXP_L0_P0 Z 56 PROG60/RGMII_TXD0/RMII_TXD0 Z
7 PCIE_RXM_L0_P0 Z 57 PROG61/RGMII_TXD1/RMII_TXD1 Z
8 VDD11PA P 58 PROG62/RGMII_TXD2 Z
9 VDD33PA P 59 PROG63/RGMII_TXD3 Z
10 PCIE_TXP_L0_P0 Z 60 PROG64/SMBUS_SCL_PU Z
11 PCIE_TXM_L0_P0 Z 61 PROG65/SMBUS_SDA_PU Z
12 VDD11PA P 62 PROG66 Z
13 VDD11PA P 63 PROG67 Z
14 VDD33PA P 64 PROG68/SERIAL_SEL_STRAP Z
15 VDD11PA P 65 VSSXTAL P
16 PCIE_TXM_L1_P0 Z 66 XTALI/CLK_IN AI
17 PCIE_TXP_L1_P0 Z 67 XTALO AO
18 VDD33PA P 68 VDD11XTAL P
19 VDD11PA P 69 VDDVARIO P
20 PCIE_RXM_L1_P0 Z 70 PROG69 Z
21 PCIE_RXP_L1_P0 Z 71 PROG70 Z
22 VDD11 P 72 PROG71 Z
23 VDD33PVTREF P 73 VDD11 P
24 VSSPVTREF P 74 VDD33A1 P
25 PROG17/PVT1 Z 75 RESET_N Z/Y
26 PROG18/PVT2 Z 76 TESTEN PD
27 VDDVARIO P 77 PCIE_PERST_N Z
28 PROG29 Z 78 PCIE_RXP_L0_P1 Z
29 PROG30 Z 79 PCIE_RXM_L0_P1 Z
30 PROG31 Z 80 VDD11PC P
31 PROG32 Z 81 VDD33PC P
32 PROG33 Z 82 PCIE_TXP_L0_P1 Z
33 VDDVARIO P 83 PCIE_TXM_L0_P1 Z
34 VSSWRPLL P 84 VDD11PC P
35 VDD33WRPLL P 85 VDD11PC P
36 PROG46/ENET_MDC Z 86 VDD33PC P
37 PROG47/ENET_MDIO Z 87 PCIE_REFCLK_IN_P Z
38 VDD11 P 88 PCIE_REFCLK_IN_M Z
39 VDDRGMII P 89 VDD11 P
40 PROG48/ENET_PHY_RESET_N Z 90 PROG75 Z
41 PROG49/ENET_DUPLEX Z 91 PROG76 Z
42 PROG50/ENET_LINK Z 92 PROG77 Z
43 PROG51/ENET_PHY_INT_N Z 93 PROG78 Z
44 PROG52/SGMII_RXP/RGMII_RX_CTL/RMII_CRS_DV Z 94 PROG79/EEPROM_STRAP Z
45 PROG53/SGMII_RXM/RGMII_RXC/RMII_REF_CLK_IN Z 95 PROG80 Z
46 PROG54/SGMII_TXP/RGMII_RXD0/RMII_RXD0 Z 96 VDD33 P
47 PROG55/SGMII_TXM/RGMII_RXD1/RMII_RXD1 Z 97 PROG81 Z
48 PROG56/SGMII_CLKM/RGMII_RXD2/RMII_RX_ER Z 98 PROG82 Z
49 PROG57/SGMII_CLKP/RGMII_RXD3 Z 99 PROG83 Z
50 VDD11ENET P 100 VDD33 P"""

rows = table.split("\n")

pins = '"Number","Name","Electrical Type","Graphic Style","Orientation","Number Text Size","Name Text Size","Length","X Position","Y Position","Visible","Unit","Body Style"\n'

for row in rows:
    cells = row.split(" ")

    # Two pins per row, 3 bits of information per pin
    assert len(cells) == 6
    for i in range(2):
        pin_num = int(cells[3 * i])
        pin_name = cells[(3 * i) + 1]
        pin_state = cells[(3 * i) + 2]
        pins += f'"{pin_num}","{pin_name}","{"Power input" if pin_state == "P" else "Unspecified"}","Line","Right","1.27","1.27","5.08","0","{pin_num * 2.54}","True","ALL","ALL"\n'

with open("PCI11010C-pins.csv", "w") as file:
    file.write(pins)

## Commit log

2026-01-26 Updated FH12-22S-0.5SH footprints
    [cm5io.kicad_sch, jabr-control-v1.kicad_pcb, mipi-connectors.kicad_sch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]
2026-04-02 Added v2 project
    [1000base-t1-connector.kicad_sch, 1000base-t1-phy.kicad_sch, 1v0-1v1-regulators.kicad_sch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]
2026-04-03 PCI11010C Schematic sheet mostly done
    [1000base-t1-connector.kicad_sch, 1000base-t1-phy.kicad_sch, 1v0-1v1-regulators.kicad_sch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]
2026-04-04 Moved M.2 buffers to new sheet
    [1000base-t1-phy.kicad_sch, 1v1-regulator.kicad_sch, 3v3-regulators.kicad_sch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]
2026-04-05 Power circuitry done
    [3v3-always-on.kicad_sch, 3v3-regulators.kicad_sch, 5v-regulator.kicad_sch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]
2026-04-05 PCI11010 IO done
    [1000base-t1-phy.kicad_sch, 5v-regulator.kicad_sch, breakout.kicad_sch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]
2026-04-06 Removed power button reset to switch (power will be cycled anyway)
    [1000base-t1-phy.kicad_sch, 3v3-always-on.kicad_sch, 5v-regulator.kicad_sch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]
2026-04-06 Schematic done
    [1000base-t1-phy.kicad_sch, 3v3-always-on.kicad_sch, 5v-regulator.kicad_sch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]
2026-04-06 Renamed everything to JABRJ
    [1000base-t1-connector.kicad_sch, 1000base-t1-phy.kicad_sch, 1v0-1v1-regulators.kicad_sch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]
2026-04-06 Fixed 5V buck inductor value
    [1000base-t1-phy.kicad_sch, 3v3-always-on.kicad_sch, 5v-regulator.kicad_sch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]
2026-04-06 Minor schematic fixes
    [1000base-t1-phy.kicad_sch, 3v3-always-on.kicad_sch, 5v-regulator.kicad_sch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]
2026-04-07 Layout started
    [5v-regulator.kicad_sch, cm5.kicad_sch, cm5io.kicad_sch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]
2026-04-08 Layout almost done
    [5v-regulator.kicad_sch, cm5.kicad_sch, cm5io.kicad_sch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]
2026-04-10 895 Unrouted
    [cm5.kicad_sch, jabrj-control-v2.kicad_pcb, mipi-connectors.kicad_sch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]
2026-04-11 651 Unrouted
    [1000base-t1-phy.kicad_sch, 5v-regulator.kicad_sch, cm5.kicad_sch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]
2026-04-12 603 Unrouted
    [5v-regulator.kicad_sch, cm5.kicad_sch, cm5io.kicad_sch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]
2026-04-12 400 Unrouted
    [5v-regulator.kicad_sch, cm5.kicad_sch, cm5io.kicad_sch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]
2026-04-12 133 Unrouted
    [5v-regulator.kicad_sch, cm5.kicad_sch, cm5io.kicad_sch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]
2026-04-14 37 Unrouted
    [pcie-switch.kicad_sch]
2026-04-17 Length matched RGMII
    [rgmii-tuning.ods]
2026-04-17 Updated all line endings
    [5v-regulator.kicad_sch, CM5IO.kicad_pcb, CM5IO.kicad_sch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]
2026-04-18 DRC Clean
    [5v-regulator.kicad_sch, cm5.kicad_sch]
2026-04-18 Renamed boards to CM5 Carriers
    [1000base-t1-connector.kicad_sch, 1000base-t1-phy.kicad_sch, 1v0-1v1-regulators.kicad_sch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]
2026-04-19 Changed UART connector to I2C
    [1000base-t1-phy.kicad_sch, 5v-regulator.kicad_sch, cm5-carrier-v2.kicad_sch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]
2026-05-30 Shortened 5V buck feedback path
